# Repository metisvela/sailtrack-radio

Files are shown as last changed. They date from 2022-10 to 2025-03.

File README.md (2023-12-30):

<p align="center">
  
</p>

<p align="center">
  
  
</p>

# SailTrack Radio

SailTrack Radio is a component of the SailTrack system, it manages GPS data and forwards messages from the SailTrack Network to [SailTrack Ground](https://github.com/metisvela/sailtrack-ground) using [LoRa](https://lora-alliance.org). To learn more about the SailTrack project, please visit the [project repository](https://github.com/metisvela/sailtrack).

The SailTrack Radio module is based on a battery powered LilyGo TTGO T-Beam, consisting of an [ESP32](https://www.espressif.com/en/products/socs/esp32) microcontroller connected to a GPS module and a LoRa transceiver. For a more detailed hardware description of the module, please refer to the [Bill Of Materials](hardware/BOM.csv). The 3D-printable enclosure con be found [here](hardware/STL).

The module performs the following tasks:

* It gets the positioning data coming from the onboard GPS module and sends them in the SailTrack Network.
* It receives the desired metrics from the SailTrack Network and forwards them to SailTrack Ground using LoRa.

<p align="center">
  <br/>
  
</p>

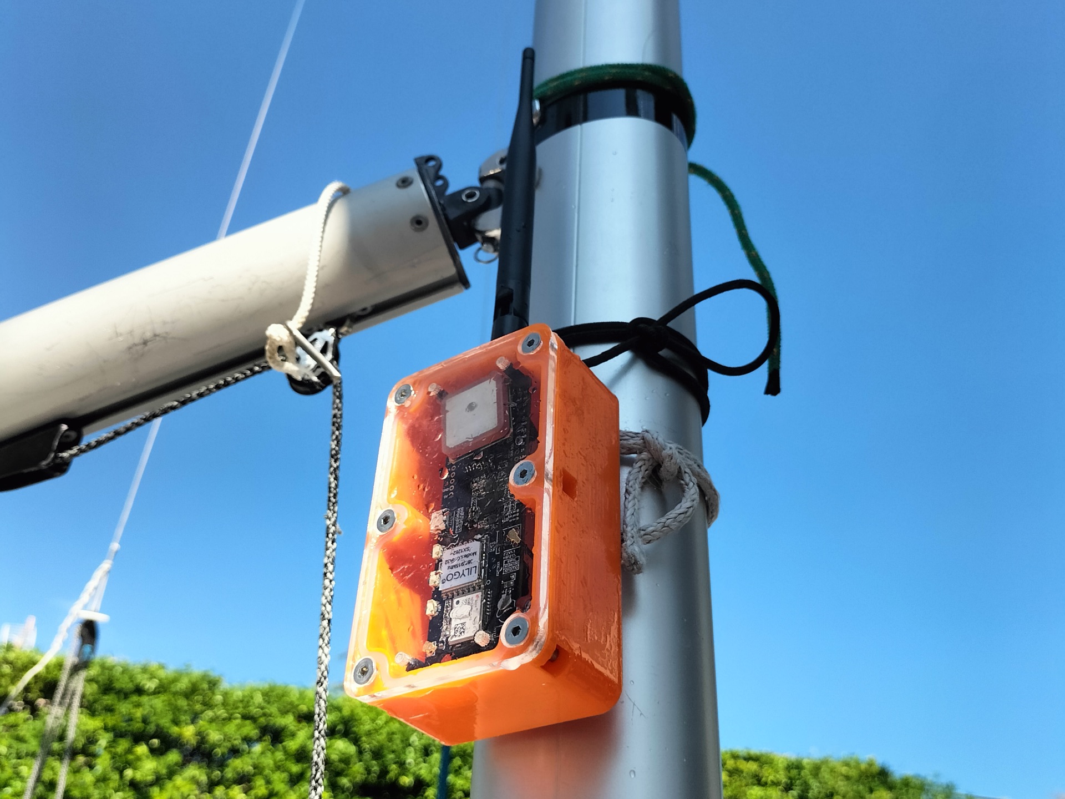
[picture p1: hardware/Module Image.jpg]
module-image


## Installation

Follow the instructions below to get the SailTrack Radio firmware correctly installed. If you encounter any problem, please [open an issue](https://github.com/metisvela/sailtrack-radio/issues/new).

1. [Install PlatformIO Core](https://docs.platformio.org/en/latest/core/installation/index.html).
2. Clone the SailTrack Radio repository:
   ```
   git clone https://github.com/metisvela/sailtrack-radio.git 
   ``` 
3. Cd into the directory:
   ```
   cd sailtrack-radio
   ```
4. **(macOS ONLY)** Uncomment the commented lines after "Patch for macOS" in the `platformio.ini` file.
5. Connect the module with an USB cable.
6. Finally, flash the firmware:
   ```
   pio run
   ```

## Usage

Once the firmware is uploaded the module can work with the SailTrack system. When SailTrack Radio is turned on, a LED start to blink to notify the user about the connection status with SailTrack Core. Then, if the connection is successful, the LED stays on, otherwise the module will put itself to sleep, and it will try to connect later. Once the module is connected it will automatically start sending measurements.

## Contributing

Contributors are welcome. If you are a student of the University of Padova, please apply for the Metis Sailing Team in the [website](http://metisvela.dii.unipd.it), specifying in the appliaction form that you are interested in contributing to the SailTrack Project. If you are not a student of the University of Padova, feel free to open Pull Requests and Issues to contribute to the project.

## License

Copyright © 2023, [Metis Sailing Team](https://github.com/metisvela). SailTrack Radio is available under the [GPL-3.0 license](https://www.gnu.org/licenses/gpl-3.0.en.html). See the LICENSE file for more info.

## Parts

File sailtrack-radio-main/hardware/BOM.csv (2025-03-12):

Part Name | Total Quantity Required | Note
LilyGo TTGO T-Beam v1.1 SX1262 + GPS NEO-M8N + ESP32 + BMS | 1
GPS Antenna | 1
LoRa Antenna | 1
u.FL to Waterproof SMA Adapter Cable | 1
NCR 18650B Li-Ion Battery 3400mAh | 1
LED RGB | 1

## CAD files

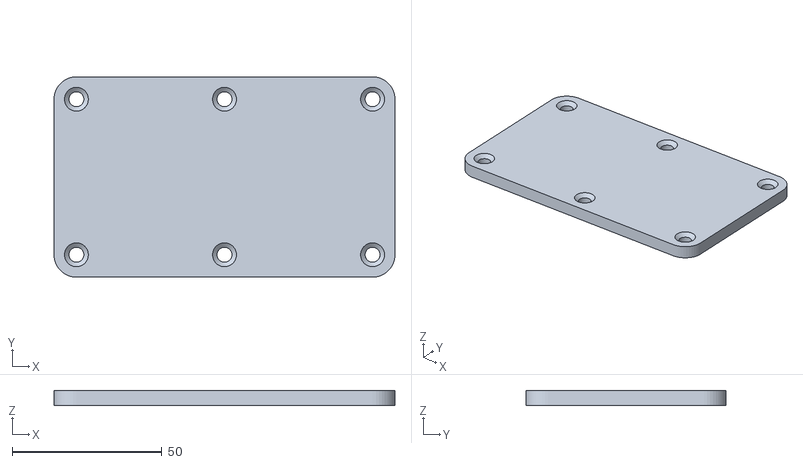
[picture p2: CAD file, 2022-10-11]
sailtrack-radio-main/hardware/STL/Case Top.stl
114.0 x 67.0 x 5.00

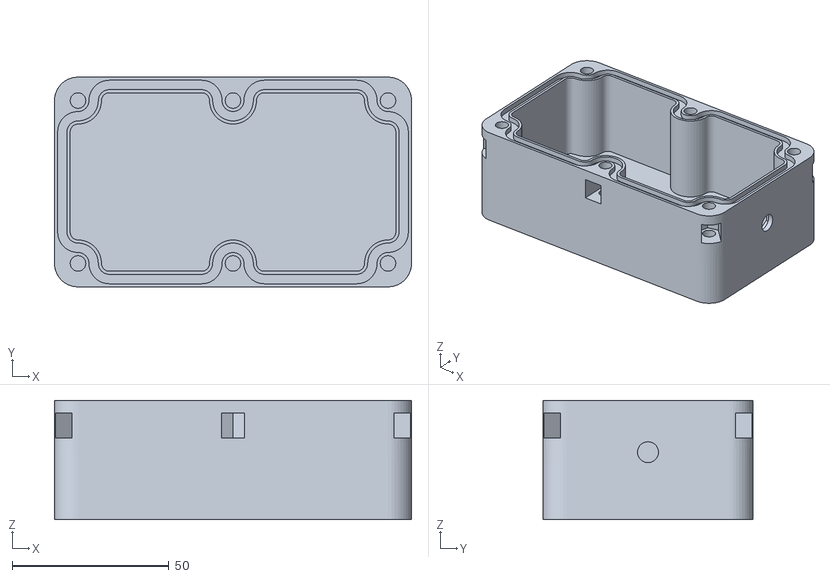
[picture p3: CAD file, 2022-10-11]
sailtrack-radio-main/hardware/STL/Case Bottom.stl
114.0 x 67.0 x 38.0

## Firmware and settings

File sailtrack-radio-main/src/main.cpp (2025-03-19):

#include <freertos/FreeRTOS.h>
#include <freertos/task.h>
#include <Arduino.h>
#include <SailtrackModule.h>
#include <XPowersLib.h>
#include <SparkFun_u-blox_GNSS_Arduino_Library.h>
#include <RadioLib.h>
#include <E32-868T20D.h>


// -------------------------- Configuration -------------------------- //

#define MQTT_PUBLISH_FREQ_HZ        5
#define LORA_SEND_FREQ_HZ           1

#define GPS_BAUD_RATE               9600
#define GPS_SERIAL_CONFIG           SERIAL_8N1
#define GPS_RX_PIN                  34
#define GPS_TX_PIN                  12
#define GPS_NAVIGATION_FREQ_HZ      MQTT_PUBLISH_FREQ_HZ

#define LORA_CS_PIN                 18
#define LORA_DIO1_PIN               33
#define LORA_RST_PIN                23
#define LORA_BUSY_PIN               32
#define LORA_MESSAGE_BUFFER_SIZE    512
#define LORA_PACKET_SIZE            64

// EBYTE E32-868T20D parameters
#define E32_CHANNEL                 0x09
#define E32_ADDRESS                 0x1310
#define E32_BASE_FREQUENCY_MHZ      862
#define E32_BANDWIDTH_KHZ           500
#define E32_SPREADING_FACTOR        11
#define E32_CODING_RATE_DENOM       5

#define LOOP_TASK_INTERVAL_MS       1000 / (2 * GPS_NAVIGATION_FREQ_HZ)
#define LORA_TASK_INTERVAL_MS       1000 / LORA_SEND_FREQ_HZ

struct LoraMetric {
    char value[32];
    char topic[32];
    char name[32];
} loraMetrics[] = {
    { "0", "sensor/gps0", "epoch" },
    { "0", "boat", "lon" },
    { "0", "boat", "lat" },
    { "0", "boat", "sog" },
    { "0", "boat", "cog" },
    { "0", "boat", "heading"},
    { "0", "boat", "pitch" },
    { "0", "boat", "roll" }
};

// ------------------------------------------------------------------- //

SailtrackModule stm;
SFE_UBLOX_GNSS gps;
XPowersLibInterface * pmu = new XPowersAXP2101(Wire);
SX1262 lora = new Module(LORA_CS_PIN, LORA_DIO1_PIN, LORA_RST_PIN, LORA_BUSY_PIN);
E32_868T20D e32;

size_t loraSentBytes = 0;
unsigned long ttff = 0;
unsigned long ttffStart;

class ModuleCallbacks: public SailtrackModuleCallbacks {
    void onStatusPublish(JsonObject status) {
        JsonObject battery = status.createNestedObject("battery");
        battery["voltage"] = pmu->getBattVoltage() / 1000.;
        battery["percentage"] = pmu->getBatteryPercent();
        JsonObject lora = status.createNestedObject("lora");
        lora["bitrate"] = loraSentBytes * 8 * STM_STATUS_PUBLISH_FREQ_HZ / 1000;
        loraSentBytes = 0;
        JsonObject gpsObj = status.createNestedObject("gps");
        gpsObj["ttff"] = ttff;
        gpsObj["aop"] = gps.getAOPSTATUSstatus();
    }

    void onMqttMessage(const char * topic, JsonObjectConst message) {
        for (int i = 0; i < sizeof(loraMetrics)/sizeof(*loraMetrics); i++) {
            LoraMetric & metric = loraMetrics[i];
            if (!strcmp(topic, metric.topic)) {
                char metricName[strlen(metric.name)+1];
                strcpy(metricName, metric.name);
                char * token = strtok(metricName, ".");
                JsonVariantConst tmpVal = message;
                while (token) {
                    if (!tmpVal.containsKey(token)) break;
                    tmpVal = tmpVal[token];
                    token = strtok(NULL, ".");
                }
                if (!token) serializeJson(tmpVal, metric.value);
            }
        }
    }
};

void loraTask(void * pvArguments) {
    TickType_t lastWakeTime = xTaskGetTickCount();
    while (true) {
        char message[LORA_MESSAGE_BUFFER_SIZE];
        strcpy(message, loraMetrics[0].value);
        strcpy(loraMetrics[0].value, "0");
        for (int i = 1; i < sizeof(loraMetrics)/sizeof(*loraMetrics); i++) {
            strcat(message, " ");
            strcat(message, loraMetrics[i].value);
            strcpy(loraMetrics[i].value, "0");
        }
        strcat(message, "\n");

        uint8_t packet[LORA_PACKET_SIZE];
        size_t len;
        size_t consumed = 0;
        size_t toConsume = strlen(message);
        pmu->enablePowerOutput(XPOWERS_ALDO2);
        while (consumed < toConsume) {
            consumed += e32.encode(E32_ADDRESS, message + consumed, packet, &len);
            lora.transmit(packet, len);
            loraSentBytes += len;
        }
        pmu->disablePowerOutput(XPOWERS_ALDO2);
        vTaskDelayUntil(&lastWakeTime, pdMS_TO_TICKS(LORA_TASK_INTERVAL_MS));
    }
}

void beginPMU() {
    pmu->init();
    // Protect the ESP32 power channel from being disabled to avoid bricking the board
    pmu->setProtectedChannel(XPOWERS_DCDC1);
    // Disable all power outputs, they will be enabled on each module's begin() function
    pmu->disablePowerOutput(XPOWERS_DCDC2);
    pmu->disablePowerOutput(XPOWERS_DCDC3);
    pmu->disablePowerOutput(XPOWERS_DCDC4);
    pmu->disablePowerOutput(XPOWERS_DCDC5);
    pmu->disablePowerOutput(XPOWERS_ALDO1);
    pmu->disablePowerOutput(XPOWERS_ALDO2);
    pmu->disablePowerOutput(XPOWERS_ALDO3);
    pmu->disablePowerOutput(XPOWERS_ALDO4);
    pmu->disablePowerOutput(XPOWERS_BLDO1);
    pmu->disablePowerOutput(XPOWERS_BLDO2);
    pmu->disablePowerOutput(XPOWERS_DLDO1);
    pmu->disablePowerOutput(XPOWERS_DLDO2);
    pmu->disablePowerOutput(XPOWERS_VBACKUP);
    // Set the battery charging current to 1A
    pmu->setChargerConstantCurr(XPOWERS_AXP2101_CHG_CUR_1000MA);
}

void beginGPS() {
    Serial.println("start begin gps");
    pmu->setPowerChannelVoltage(XPOWERS_ALDO1, 3300);
    pmu->setPowerChannelVoltage(XPOWERS_ALDO3, 3300);
    pmu->setPowerChannelVoltage(XPOWERS_VBACKUP, 3300);
    pmu->enablePowerOutput(XPOWERS_ALDO3);
    pmu->enablePowerOutput(XPOWERS_ALDO1);
    pmu->enablePowerOutput(XPOWERS_VBACKUP);
    Serial1.begin(GPS_BAUD_RATE, GPS_SERIAL_CONFIG, GPS_RX_PIN, GPS_TX_PIN);
    gps.begin(Serial1);
    gps.setUART1Output(COM_TYPE_UBX);
    gps.setDynamicModel(DYN_MODEL_SEA);
    gps.setNavigationFrequency(GPS_NAVIGATION_FREQ_HZ);
    gps.setAutoPVT(true);
    gps.setAopCfg(1);
    ttffStart = millis();
}

void beginLora() {
    pmu->setPowerChannelVoltage(XPOWERS_ALDO2, 3300);
    pmu->enablePowerOutput(XPOWERS_ALDO2);
    lora.begin(E32_BASE_FREQUENCY_MHZ + E32_CHANNEL, E32_BANDWIDTH_KHZ, E32_SPREADING_FACTOR, E32_CODING_RATE_DENOM);
    for (auto metric : loraMetrics) stm.subscribe(metric.topic);
    xTaskCreate(loraTask, "loraTask", STM_TASK_MEDIUM_STACK_SIZE, NULL, STM_TASK_MEDIUM_PRIORITY, NULL);
}
//Task di controllo
void task1(void *parameter){
    while (true)
    {
        Serial.println("[TASK] operating");
        if(pmu->isCharging()){
            Serial.println("[TASK] battery is charging");

        }else{
            Serial.print("[TASK] Battery is NOT charging");
            pmu->setChargerConstantCurr(XPOWERS_AXP2101_CHG_CUR_1000MA);
        }
        vTaskDelay(2000/portTICK_PERIOD_MS);
    }
    
}
void setup() {
    Serial.begin(115200);
    xTaskCreate(task1,"task1",2048,NULL,1, NULL);
    beginPMU();
    stm.begin("radio", IPAddress(192, 168, 42, 101), new ModuleCallbacks());
    beginGPS();
    beginLora();
}

void loop() {
    TickType_t lastWakeTime = xTaskGetTickCount();
    if (gps.getPVT() && gps.getTimeValid()) {
        if (!ttff && gps.getFixType() >= 2) ttff = millis() - ttffStart;
        StaticJsonDocument<STM_JSON_DOCUMENT_MEDIUM_SIZE> doc;
        doc["fixType"] = gps.getFixType(); 			// GNSS fix Type: 0 = no fix, 1 = dead reckoning only, 2 = 2D-fix, 3 = 3D-fix
        doc["epoch"] = gps.getUnixEpoch();			// Get the current Unix epoch time rounded to the nearest second
        doc["lon"] = gps.getLongitude();			// Longitude: deg * 1e-7
        doc["lat"] = gps.getLatitude();				// Latitude: deg * 1e-7
        doc["hMSL"] = gps.getAltitudeMSL();			// Height above mean sea level: mm
        doc["hAcc"] = gps.getHorizontalAccEst();	// Horizontal accuracy estimate: mm
        doc["vAcc"] = gps.getVerticalAccEst();		// Vertical accuracy estimate: mm
        doc["velN"] = gps.getNedNorthVel();			// NED north velocity: mm/s
        doc["velE"] = gps.getNedEastVel();			// NED east velocity: mm/s
        doc["velD"] = gps.getNedDownVel();			// NED down velocity: mm/s
        doc["gSpeed"] = gps.getGroundSpeed();		// Ground Speed (2-D): mm/s
        doc["headMot"] = gps.getHeading();			// Heading of motion (2-D): deg * 1e-5
        doc["sAcc"] = gps.getSpeedAccEst();			// Speed accuracy estimate: mm/s
        doc["headAcc"] = gps.getHeadingAccEst();	// Heading accuracy estimate (both motion and vehicle): deg * 1e-5
        stm.publish("sensor/gps0", doc.as<JsonObjectConst>());
    }
    vTaskDelayUntil(&lastWakeTime, pdMS_TO_TICKS(LOOP_TASK_INTERVAL_MS));
}

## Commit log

2021-07-06 Added submodule lib/sailtrack-sensor
2021-07-25 Updated submodule lib/sailtrack-sensor
2021-08-01 Delegated power managment
2022-02-17 Add hardware files
    [BOM.csv, case-bottom.stl, case-top.stl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]
2022-05-02 Use new metric names + fix tokenization
    [main.cpp]
2022-06-19 Update hardware files
    [Case Bottom.stl, Case Top.stl, case-bottom.stl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]
2022-07-30 rework on mqtt topics
    [main.cpp]
2024-04-12 Add battery datasheet
2024-07-29 optimize power consumption in lora
2025-03-12 Update BOM.csv
    Update and validation of matirial:
    u.FL to Waterproof SMA Adapter Cable, 1,
    LED RGB,1,
    [BOM.csv]
